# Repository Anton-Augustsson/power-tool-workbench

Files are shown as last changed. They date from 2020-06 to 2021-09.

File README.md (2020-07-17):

# Power tool workbench
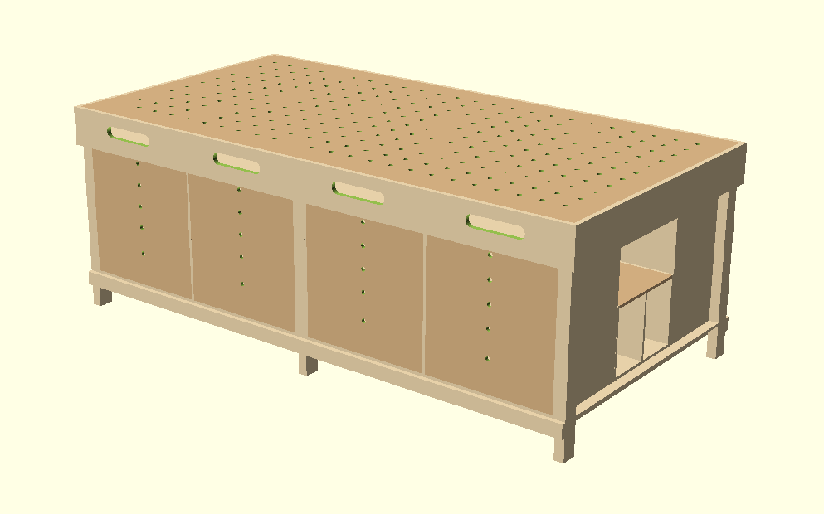
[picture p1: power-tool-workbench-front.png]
power-tool-workbench-front

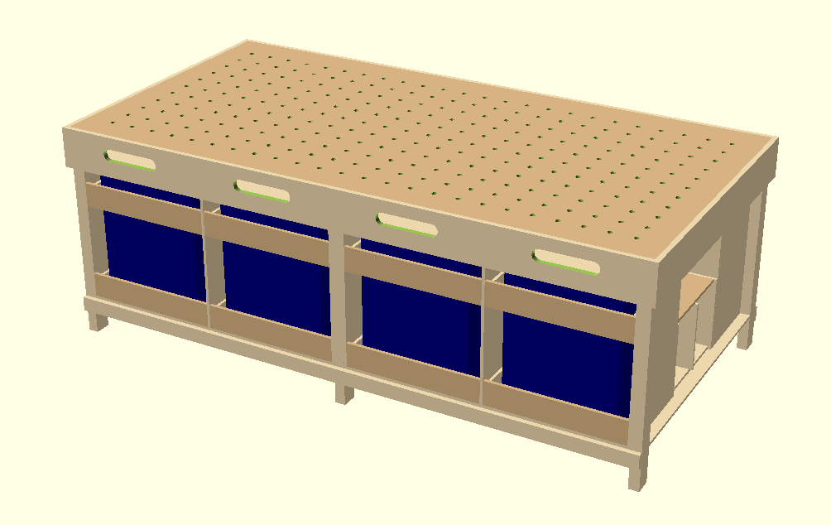
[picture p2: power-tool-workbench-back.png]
power-tool-workbench-back


## Equipment
### The patf guide system
https://www.axminstertools.com/ujk-technology-parf-guide-system-102278

### Accessories
https://www.axminstertools.com/ujk-technology-50mm-guide-dog-105310
https://www.axminstertools.com/ujk-technology-parf-repeat-stop-105103?sel=105103
https://www.axminstertools.com/ujk-technology-parf-system-fence-106824
https://www.axminstertools.com/ujk-technology-accessory-kit-in-t-loc-case-106161

https://www.axminstertools.com/veritas-wonder-pup-202393

### Building materials

door slides 
https://www.biltema.se/bygg/gangjarn/specialgangjarn/expansionsbeslag-2-st-2000018657
https://www.hornbach.se/shop/Rullskena-HABO-230-vitlack-400mm-1par/7122220/artikel-detaljer.html

## Instuctions
1. Lay all shets, mdf and plywood, att a flat serfice with waight so the are fores to be flat.
2. Saw all lists for the top exactly the same width. Then laythem out and cut the lenght.
   Do the same with the edges
3. Use the dges as frames to incapsulate the list by screwing to the edge of the plywood, 
   you need somting under the plywood inorder to get the desigerd edge posision. 
   Then screw the lists in plase.
4. Saw legs and shelf list, make sure the corespond to the distens of the plywood and the edge.
5. Mark accuratly the position for the self list, make sure the legs are squared. 
   Then srew the lists in plase, prediril first.
6. Screw the top into the legs. Then disasembel the edges.
7. Use a level and a plane to make the list flush and level. It is critical to get this right.
   You can use the mdf as an extension of the level.
8. Use the path guide system to make holes. Have the mdf on the bench during that time.
   Then Screw back the edges to encapulate the mdf.

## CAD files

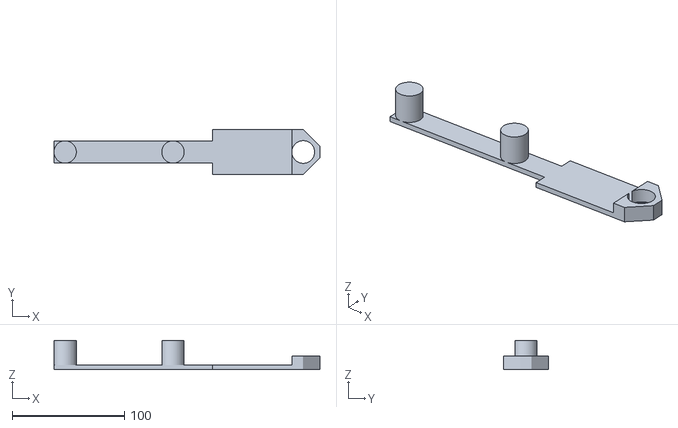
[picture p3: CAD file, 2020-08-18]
cad/parf-full-sheet-extension/parf-full-cheet-extension.stl
236.9 x 39.8 x 26.0

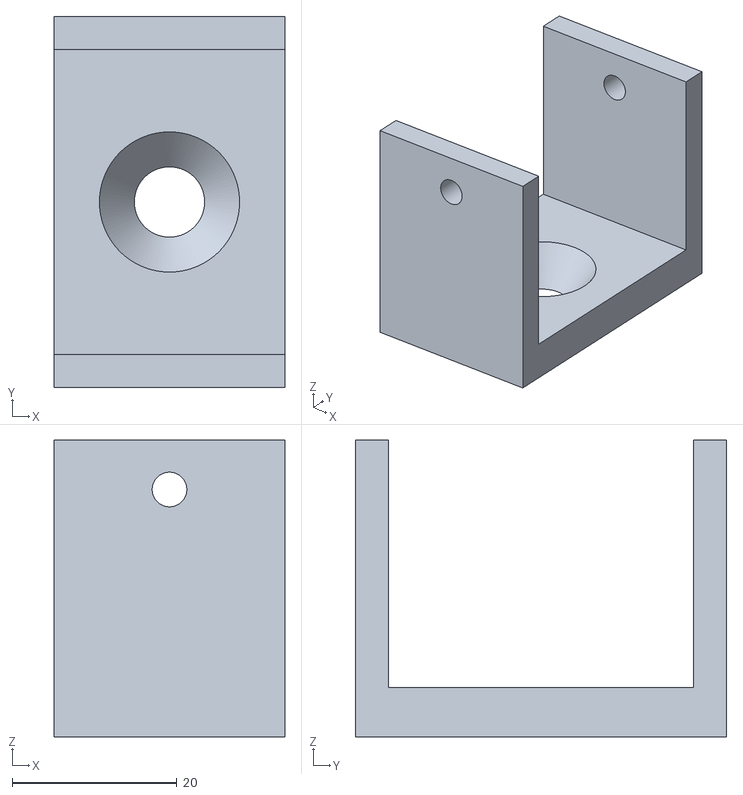
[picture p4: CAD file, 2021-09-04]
cad/cross-country-skiing-mounts/skiing-mounts-boot.stl
28.0 x 45.0 x 36.0

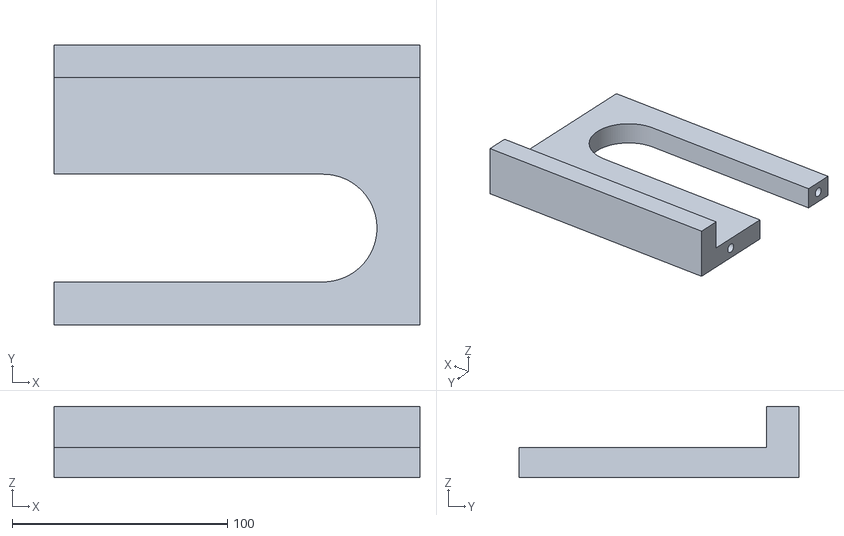
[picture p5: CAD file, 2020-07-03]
cad/module/3d-print/template-removal-side-holes-female.stl
170.0 x 130.0 x 33.0

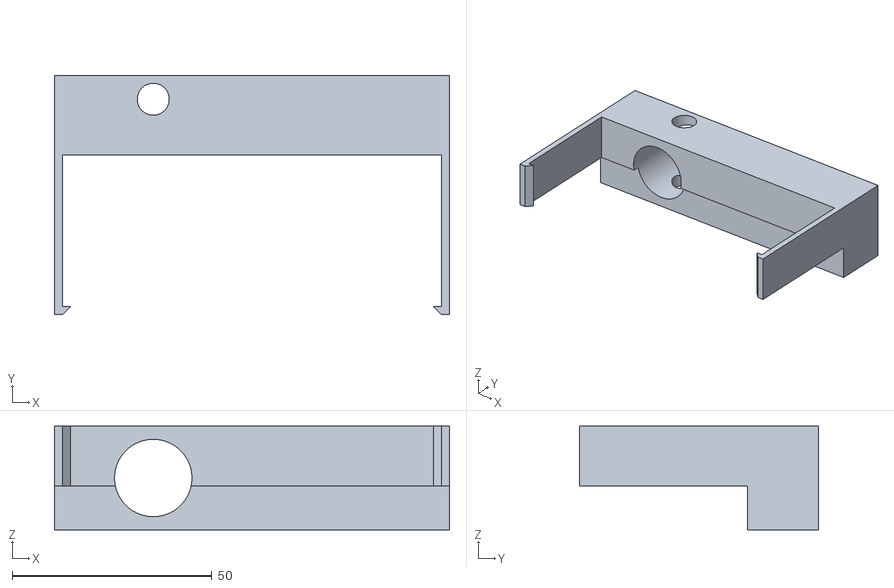
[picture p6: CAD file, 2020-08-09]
cad/parf-dust-port/print/parf-dust-port.stl
99.0 x 60.0 x 26.0

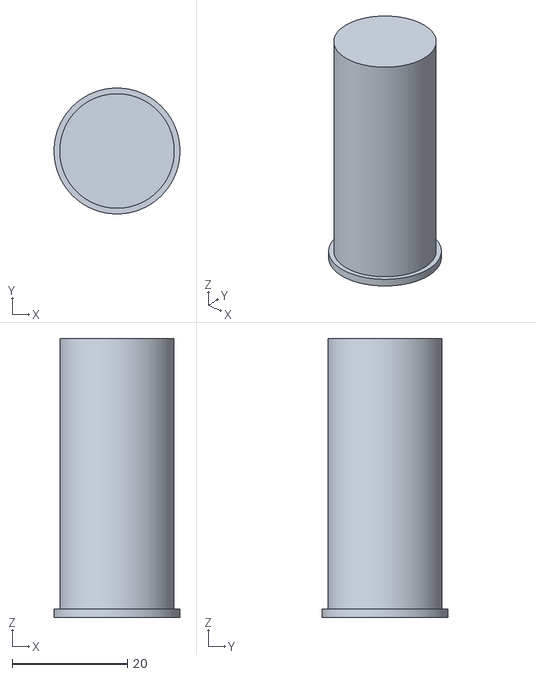
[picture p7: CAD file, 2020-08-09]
cad/parf-storage-wall/print/hanger.stl
21.9 x 21.9 x 48.5

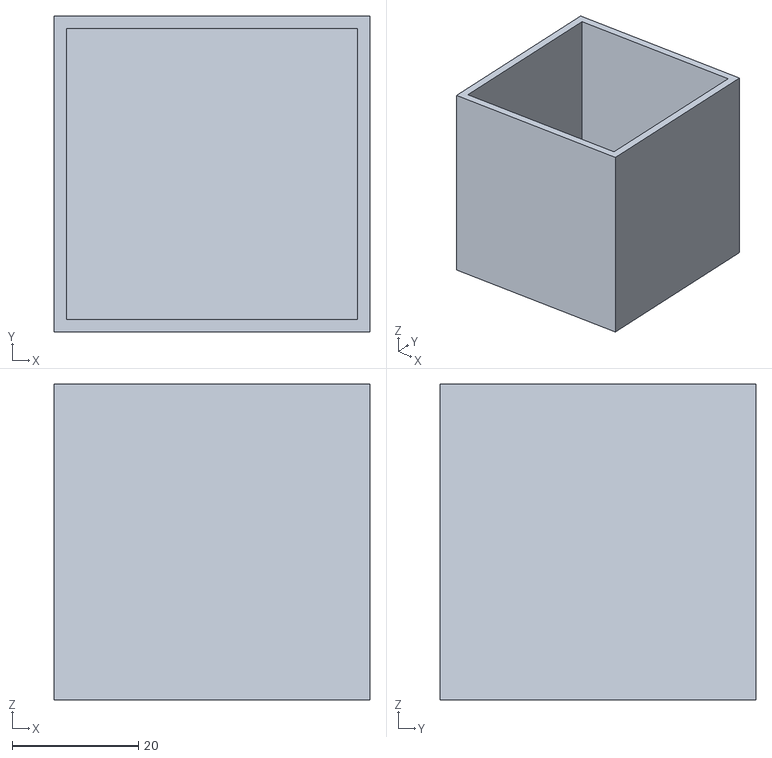
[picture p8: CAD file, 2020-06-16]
cad/sorting-boxes/stl/1x1.stl
50.0 x 50.0 x 50.0

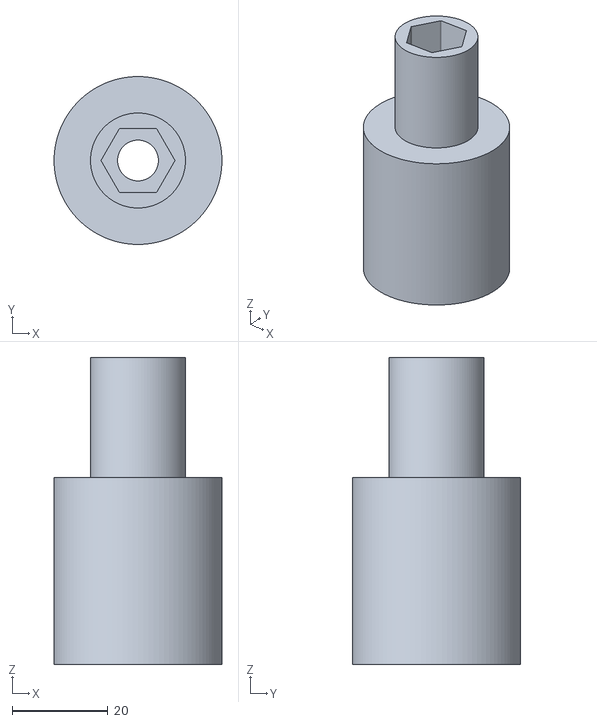
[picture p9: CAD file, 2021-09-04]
cad/cross-country-skiing-mounts/parth-skii-mount.stl
35.0 x 35.0 x 64.0

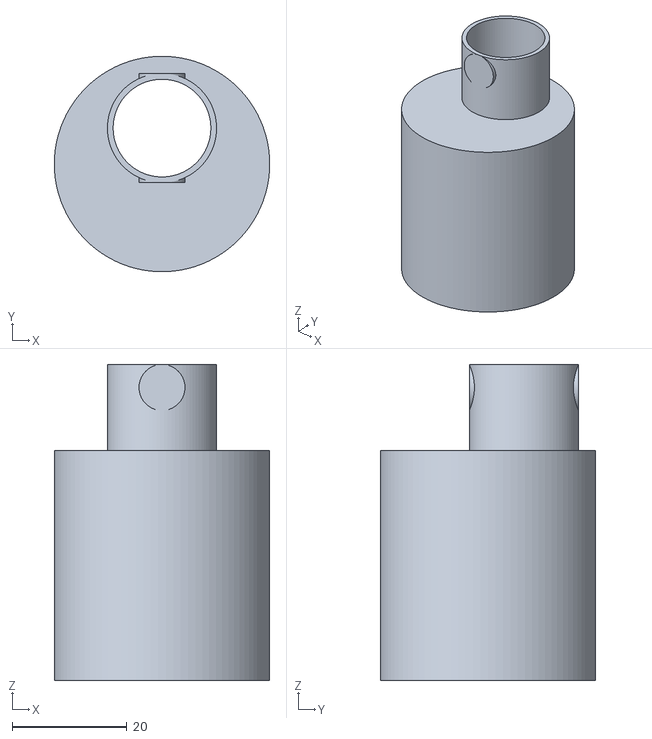
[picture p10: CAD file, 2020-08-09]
cad/parf-dust-port/print/hose-adapter.stl
37.5 x 37.5 x 55.0

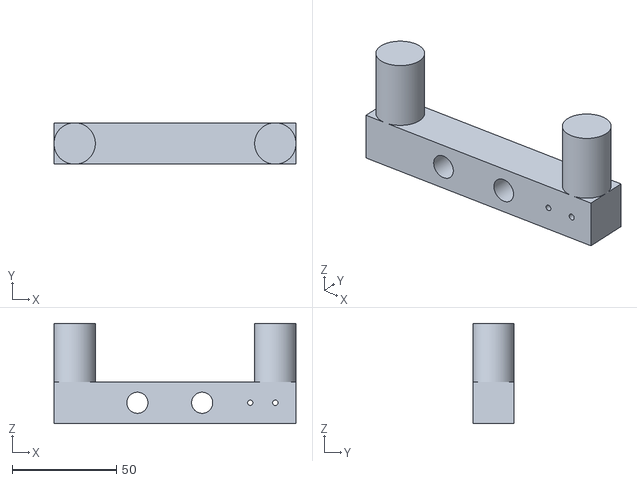
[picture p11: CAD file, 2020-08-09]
cad/parf-storage-wall/print/drill-holder.stl
115.8 x 19.8 x 48.0

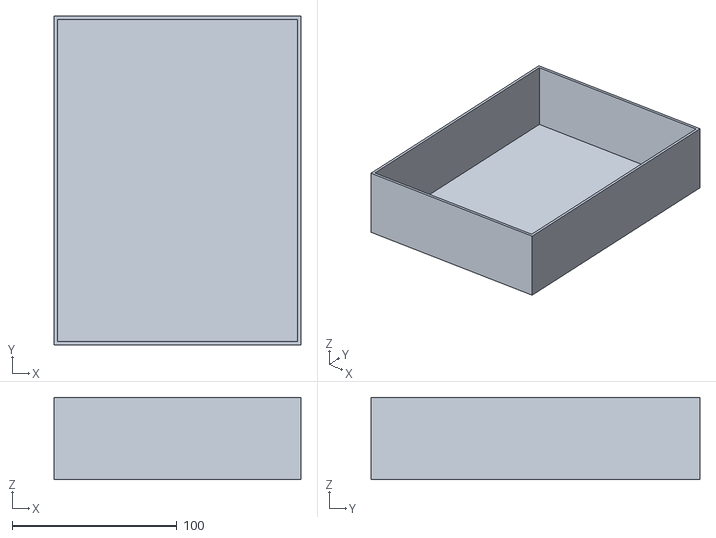
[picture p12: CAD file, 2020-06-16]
cad/sorting-boxes/stl/3x4.stl
150.0 x 200.0 x 50.0

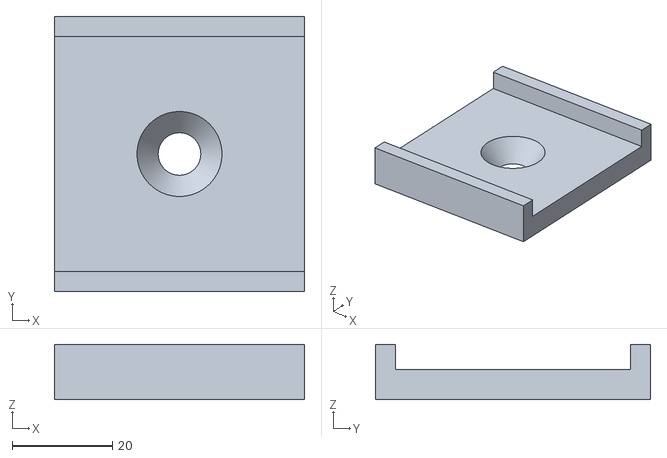
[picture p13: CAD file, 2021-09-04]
cad/cross-country-skiing-mounts/skiing-mounts.stl
50.0 x 55.0 x 11.0

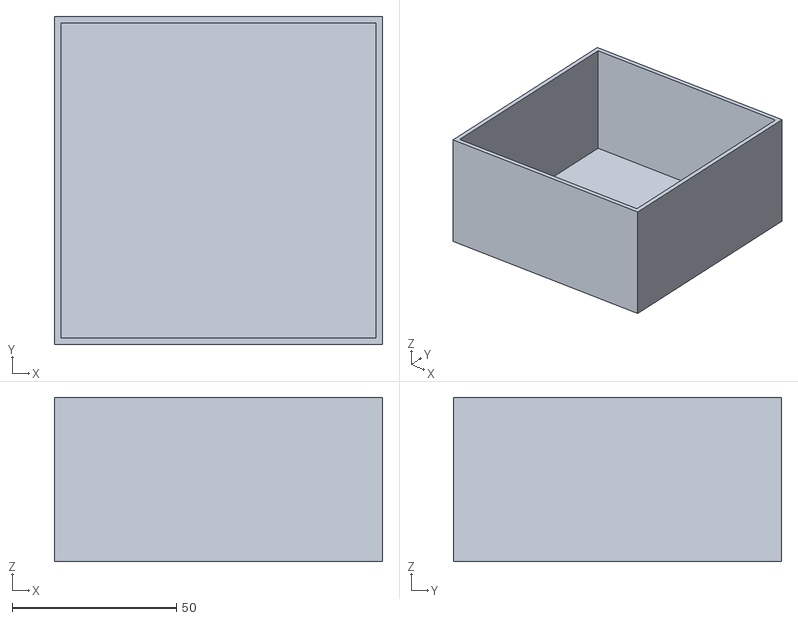
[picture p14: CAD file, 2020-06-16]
cad/sorting-boxes/stl/2x2.stl
100.0 x 100.0 x 50.0

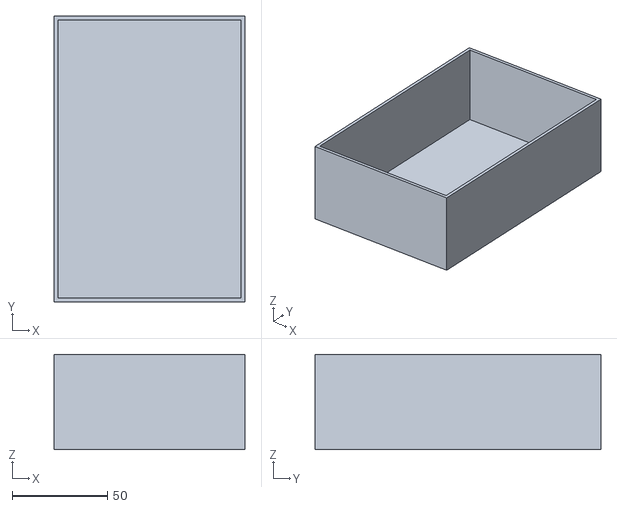
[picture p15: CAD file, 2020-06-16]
cad/sorting-boxes/stl/2x3.stl
100.0 x 150.0 x 50.0

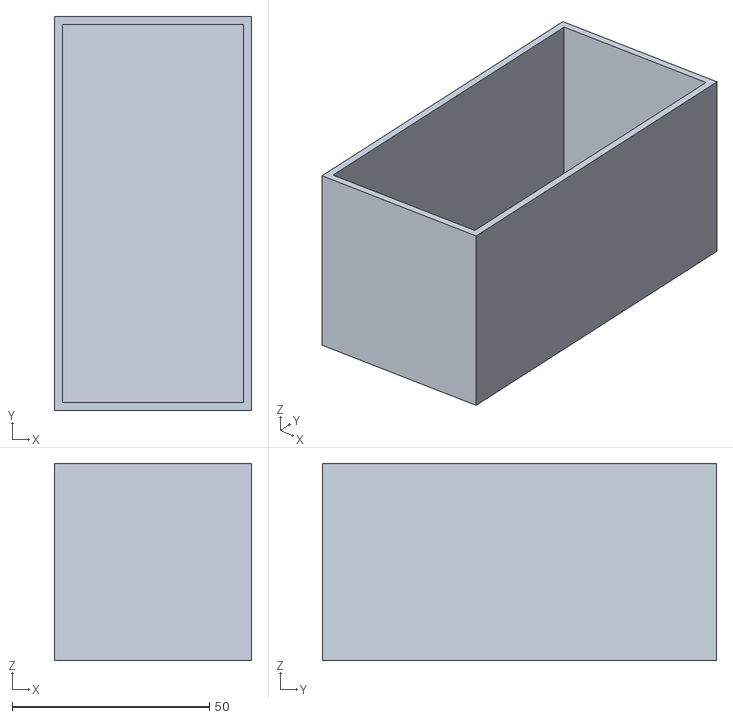
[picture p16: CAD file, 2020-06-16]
cad/sorting-boxes/stl/1x2.stl
50.0 x 100.0 x 50.0

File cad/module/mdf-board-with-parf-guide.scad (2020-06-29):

/*

    MDF Board With Parf Guide
    
    By Anton Augustsson


*/


module mdfBoardWithParfGuide (
    standardSheathingWidth,
    standardSheathingLength,
    mdfTopThickness,
    x,y,z
    ){
/*
    ---------- Local varibles ---------- 
*/

startX = 120;
startY = startX;

parfHoles = 10; //20mm 
betweedHoles = 96;

/*
    ---------- Code ---------- 
*/

translate([
    x,
    y,
    z])
difference() { 
union () {

// mdf top
color("BurlyWood")
translate([
    0,
    0,
    0]) 
cube(size = [
    standardSheathingLength,
    standardSheathingWidth,
    mdfTopThickness]);

}

union () {

for(i = [
    1:
    1: 
    (standardSheathingLength-startX)
    /betweedHoles])
for(x = [
    1:
    1: 
    (standardSheathingWidth-startY)
    /betweedHoles])
translate([
    startX+betweedHoles*(i-1),
    startY+betweedHoles*(x-1),
    -1
    ])  
cylinder(
    h=mdfTopThickness+2,
    r=parfHoles
    );
// parf guide holes

}

}}
    
/*
    ---------- Example ---------- 
*/

standardSheathingWidth = 1220; 
standardSheathingLength = 2440;

mdfTopThickness = 19;
plywoodTopThickness = 12;

// Side protection for ply and mdf
edgeTopThickness = 20; 
edgeTopWidth = 167;
edgeTopLengthX = standardSheathingLength
    +2*edgeTopThickness;
edgeTopLengthY = standardSheathingWidth
    +2*edgeTopThickness;

// 4 list betweend mdf and ply (Pine)
listTopThickness = 20; 
listTopWidth = 80;
listTopLengthX = standardSheathingLength/4
    -listTopThickness;
listTopLengthY = standardSheathingWidth;

// 6 legs (Pine)
legLength = 900
    -plywoodTopThickness
    -mdfTopThickness
    -listTopWidth;
legWidth = 69;
legThickness = 42;

// 3 bottom list (Pine)
listBottomThickness = 20; 
listBottomWidth1 = 60;
listBottomWidth2 = listBottomWidth1
    -plywoodTopThickness;
listBottomLengthX = standardSheathingLength;
listBottomLengthY = standardSheathingWidth;
listBottomLengthY2 = standardSheathingWidth
    +listBottomThickness*2;
bottomHeight = 100;

storageUnitLength=standardSheathingLength/2
    -legThickness*3/2;
storageUnitWidth=400;  
storageUnitHeight=(900-edgeTopWidth)
    -(bottomHeight+listBottomWidth2);
storageUnitThickness=12;


thickness= 12;

length = 500;
width  = 600;
height = 400;

x=0;
y=0;
z=plywoodTopThickness
    +listTopWidth;
yRotate=0;

mdfBoardWithParfGuide (
    standardSheathingWidth,
    standardSheathingLength,
    mdfTopThickness,
    x,y,z
    );

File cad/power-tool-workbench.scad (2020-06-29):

/*

    Power tool workbench
    
    By Anton Augustsson
    
    
*/

//https://www.hornbach.se/shop/MDF-Board-19x2440x1220-mm/5115465/artikel-detaljer.html
//https://www.hornbach.se/shop/Furuplywood-BB-X-12x1220x2440-mm-WBP-LIM/5507269/artikel-detaljer.html
use <module/simple-drawer.scad>;
use <module/sliding-shelf.scad>;
use <module/storage-unit.scad>;
use <module/power-tool-storage.scad>;
use <module/drawer-storage.scad>;
use <module/middle-storage-unit.scad>;
use <module/top.scad>;
use <module/bottom.scad>;

/*
    ---------- Variables ---------- 
*/

standardSheathingWidth = 1220; 
standardSheathingLength = 2440;

mdfTopThickness = 19;
plywoodTopThickness = 12;

// Side protection for ply and mdf
edgeTopThickness = 20; 
edgeTopWidth = 167;
edgeTopLengthX = standardSheathingLength
    +2*edgeTopThickness;
edgeTopLengthY = standardSheathingWidth
    +2*edgeTopThickness;

// 4 list betweend mdf and ply (Pine)
listTopThickness = 20; 
listTopWidth = 80;
listTopLengthX = standardSheathingLength/4
    -listTopThickness;
listTopLengthY = standardSheathingWidth;

// 6 legs (Pine)
legLength = 900
    -plywoodTopThickness
    -mdfTopThickness
    -listTopWidth;
legWidth = 69;
legThickness = 42;

// 3 bottom list (Pine)
listBottomThickness = 20; 
listBottomWidth1 = 60;
listBottomWidth2 = listBottomWidth1
    -plywoodTopThickness;
listBottomLengthX = standardSheathingLength;
listBottomLengthY = standardSheathingWidth;
listBottomLengthY2 = standardSheathingWidth
    +listBottomThickness*2;
bottomHeight = 100;

storageUnitLength=standardSheathingLength/2
    -legThickness*3/2;
storageUnitWidth=400;  
storageUnitHeight=(900-edgeTopWidth)
    -(bottomHeight+listBottomWidth2);
storageUnitThickness=12;

/*
    ---------- Code ---------- 
*/

// ---------- Storage Unit ----------

// left storageUnit
powerToolStorage (
    storageUnitThickness,
    storageUnitLength,
    storageUnitWidth,
    storageUnitHeight,
    legThickness,
    0,
    bottomHeight+listBottomWidth2
    +plywoodTopThickness
    );

// Right storageUnit
powerToolStorage (
    storageUnitThickness,
    storageUnitLength,
    storageUnitWidth,
    storageUnitHeight,
    legThickness*2+storageUnitLength,
    0,
    bottomHeight+listBottomWidth2
    +plywoodTopThickness
    );


// Left back storageUnit
drawerStorage (
    storageUnitThickness,
    storageUnitLength,
    storageUnitWidth,
    storageUnitHeight,
    legThickness+storageUnitLength,
    standardSheathingWidth-storageUnitWidth
    +storageUnitWidth,
    bottomHeight+listBottomWidth2
    +plywoodTopThickness,
    180
    );
    

// Right back storageUnit
drawerStorage (
    storageUnitThickness,
    storageUnitLength,
    storageUnitWidth,
    storageUnitHeight,
    legThickness*2+storageUnitLength*2,
    standardSheathingWidth-storageUnitWidth
    +storageUnitWidth,
    bottomHeight+listBottomWidth2
    +plywoodTopThickness,
    180
    );


middleStorageUnit (
    storageUnitThickness,
    standardSheathingLength-legThickness*2,
    standardSheathingWidth
    -storageUnitWidth*2,
    300,
    legThickness,        
    (storageUnitWidth)*2
    +storageUnitThickness/5*8,
    bottomHeight+listBottomWidth2
    +plywoodTopThickness,
    -90
    );
    



// ---------- Bottom ----------

bottom (
    standardSheathingWidth,
    standardSheathingLength,
    plywoodTopThickness,
    legLength,
    legWidth,
    legThickness,
    listBottomThickness,
    listBottomWidth1,
    listBottomLengthX,
    listBottomLengthY,
    listBottomLengthY2,
    bottomHeight,
    0,0,0
    );
    
    
// ---------- Top ----------

top (
    standardSheathingWidth,
    standardSheathingLength,
    mdfTopThickness,
    plywoodTopThickness,
    edgeTopThickness,
    edgeTopWidth,
    edgeTopLengthX,
    edgeTopLengthY,
    listTopThickness,
    listTopWidth,
    listTopLengthX,
    listTopLengthY,
    0,0,legLength
    );
    

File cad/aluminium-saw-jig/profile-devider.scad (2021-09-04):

totLen   = 275;
totWid   =
totThick =

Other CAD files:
cad/module/3d-print/template-removal-side-holes-male.stl
cad/sorting-boxes/stl/2x4.stl
cad/sorting-boxes/stl/1x3.stl
cad/sorting-boxes/stl/4x4.stl
cad/cross-country-skiing-mounts/cross-country-skiing-mounts.scad
cad/module/bottom.scad
cad/module/drawer-storage.scad
cad/module/middle-storage-unit.scad
cad/module/power-tool-storage.scad
cad/module/removal-side-holes.scad
cad/module/simple-drawer.scad
cad/module/sliding-shelf.scad
cad/module/storage-unit.scad
cad/module/template-removal-side-holes-female.scad
cad/module/template-removal-side-holes-male.scad
cad/module/top.scad
cad/parf-dust-port/hose-adapter.scad
cad/parf-dust-port/parf-dust-port.scad
cad/parf-full-sheet-extension/parf-full-cheet-extension.scad
cad/parf-storage-wall/drill-holder.scad
cad/parf-storage-wall/hanger.scad
cad/sorting-boxes/SortBox.scad
cad/sorting-boxes/stl.scad
cad/sorting-boxes/stl/1x4.stl
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

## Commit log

2020-05-25 done withe the consept 3d drawing
    [power-tool-workbench.scad]
2020-05-29 bench review
    [power-tool-workbench.scad]
2020-06-09 taller edges
    [power-tool-workbench.scad]
2020-06-16 storage unit reprecentation
    [1x1.stl, 1x2.stl, 1x3.stl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]
2020-06-17 middle storage
    [power-tool-workbench.scad]
2020-06-27 created 3 moduels for the storage system
    [power-tool-workbench.scad, simple-drawer.scad, sliding-shelf.scad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]
2020-06-28 implemented storage system on bench
    [drawer-storage.scad, middle-storage-unit.scad, power-tool-storage.scad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]
2020-06-28 module for top
    [power-tool-workbench.scad, top.scad]
2020-06-29 removal edges holes
    [bottom.scad, power-tool-workbench.scad, removal-side-holes.scad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]
2020-06-29 parf guide holes and for loop for removal edges holes
    [mdf-board-with-parf-guide.scad, top.scad]
2020-07-03 router template
    [template-removal-side-holes-female.scad, template-removal-side-holes-female.stl, template-removal-side-holes-male.scad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]
2020-08-01 parf dust port
    [parf-dust-port.scad]
2020-08-03 parf hose adapter rev1
    [hose-adapter.scad, parf-dust-port.scad, parf-dust-port.stl]
2020-08-09 parf drill hanger
    [drill-holder.scad, drill-holder.stl, hanger.scad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]
2020-08-18 parf full sheet extension added
    [parf-full-cheet-extension.scad, parf-full-cheet-extension.stl]
2021-09-04 change size of ski mount fits now
    [cross-country-skiing-mounts.scad, parth-skii-mount.stl, profile-devider.scad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]
